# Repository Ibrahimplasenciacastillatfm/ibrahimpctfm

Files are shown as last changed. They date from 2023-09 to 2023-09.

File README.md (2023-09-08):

# ibrahimpctfm
Proyecto destinado al Diseño y Desarrollo de un Sensor IoT comunicado con Nodo Central para la Medida del Recurso Solar en Vehículos con Integración Fotovoltaica

En el repositorio se incluyen los siguientes archivos:

- Anexo_IV_Hojas_de_caracteristicas_componentes --> Enlaces a las hojas e caracteristicas de los componentes adquiridos para el diseño
- Anexo_VI_ESP32_Sensor_IoT_code.ino --> Código implementado en el sensor IoT, basado en un microcontrolador ESP32 Bluetooth & Wifi Battery (programado en Arduino IDE, C++) para la recogida de datos de irradiancia solar y temperatura empleando un módulo solar fotovoltaico de 0.3W y un termistor NTC.
- Anexo_VI_Raspi_central_node_code.py --> Código implementado en el nodo central para la recogida y registro de lso datos enviados por el sensor IoT (irradiancia solar y temperatura), así como los datos de ubicación (latitud y longitud) y orientación (magnetómetro HMC5883L) recibidos de un módulo BN-880 GPS. Basado en una Raspberry Pi 3 Model B v1.2 (programado en Python).
- ANEXO_VII_Calibracion_Modulo_Solar_Fotovoltaico --> Datos y resultados obtenidos de la calibración del Módulo Solar Fotovoltaico
-  ANEXO_VIII_Calibracion_Canales_ESP32 --> Datos y resultados obtenidos de la calibración de los canales del ESP32 empleados para la medida de la irradiancia solar y la temperatura (pines 26 y 35).
-  Archivos de diseño de la carcasa diseñada para el dispositivo sensor (en formato .ipt y .stl). El formato .ipt es el empleado por el programa Inventor Professional (se ha usado al versión 2021), mientras que el formato .stl es el empleado para las impresoras 3D. El diseño se compone de 4 piezas:
    - Pieza_base_TFM --> Parte inferior de la carcasa a la que se fija la electrónica
    - Pieza_tapa_TFM --> Parte superior de cierre del conjunto y soporte para el módulo solar fotovoltaico
    - Tapa_1_TFM --> Pieza de cierre del hueco del interruptor del ESP32
    - Tapa_2_TFM --> Pieza de cierre del hueco del conector USB del ESP32
- ANEXO_IX_Resultados_Prueba_Carretera --> Datos registrados por el sistema diseñado y desarrollado en este TFM como prueba de validación del sistema. Se corresponde con los datos recogidos en una prueba en carretera con el equipo montado en un vehículo real, bajo unas condiciones de conducción reales.

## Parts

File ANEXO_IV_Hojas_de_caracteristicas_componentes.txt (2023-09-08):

ESP32 Wifi & Bluetooth Battery
Microcontrolador del dispositivo sensor:
https://www.espressif.com/sites/default/files/documentation/esp32_datasheet_en.pdf

RS PRO, 3.7V, 18650, Lithium-Ion Rechargable Battery, 2.6Ah
Batería para el microcontrolador del dispositivo sensor
https://docs.rs-online.com/9c01/A700000008874176.pdf

Módulo Solar Fotovoltaico 100mA, 3V, 0.3W, 65x48mm
Módulo solar fotovoltaico
https://www.amazon.es/Solares-Peque%C3%B1as-C%C3%A9lulas-Proyectos-Cient%C3%ADficos/dp/B0B5XR5CQV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

Módulo AD620
Amplificador de instrumentación
https://www.amazon.es/Amplificador-Voltaje-Microvoltios-Instrumentaci%C3%B3n-Transmisor/dp/B0BQ5CYBZ4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

Termistor NTC
Sensor de temperatura
https://panda-bg.com/datasheet/918-103844-Thermistor-NTC-500mW-5-VISHAY.pdf

Raspberry Pi 3 Model B v1.2
Microcontrolador del dispositivo central
https://components101.com/sites/default/files/component_datasheet/Raspberry%20Pi%203%20Datasheet.pdf

Módulo BN-880 GPS
GPS y Brújula
https://maxterdrone.com/es/modulos-gps/1193-beitian-bn-880-gps.html

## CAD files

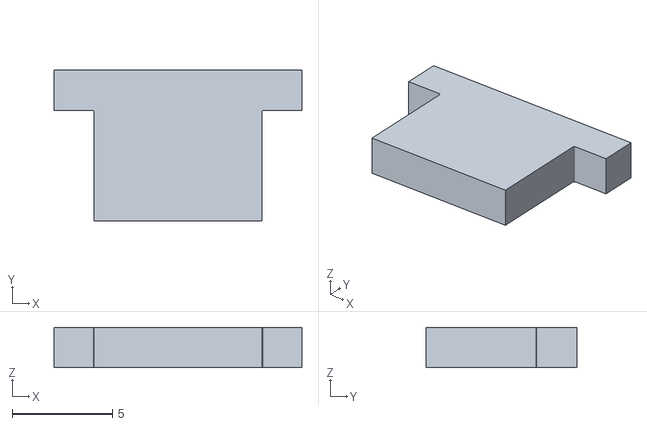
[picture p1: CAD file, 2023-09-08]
Tapa_2_TFM.stl
12.4 x 7.50 x 2.00

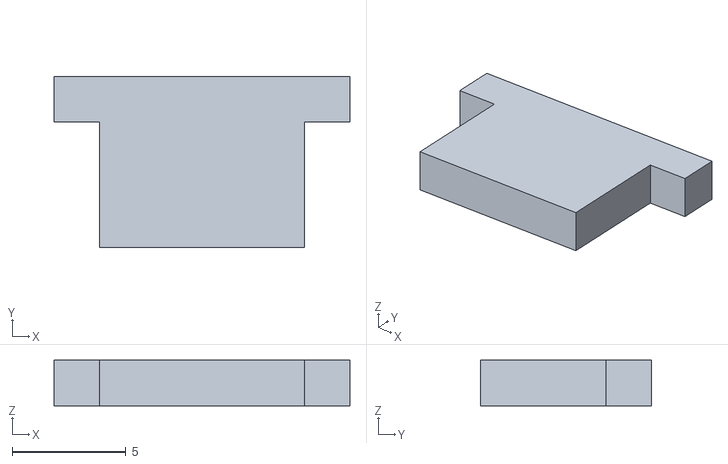
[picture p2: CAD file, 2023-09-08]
Tapa_1_TFM.stl
13.0 x 7.50 x 2.00

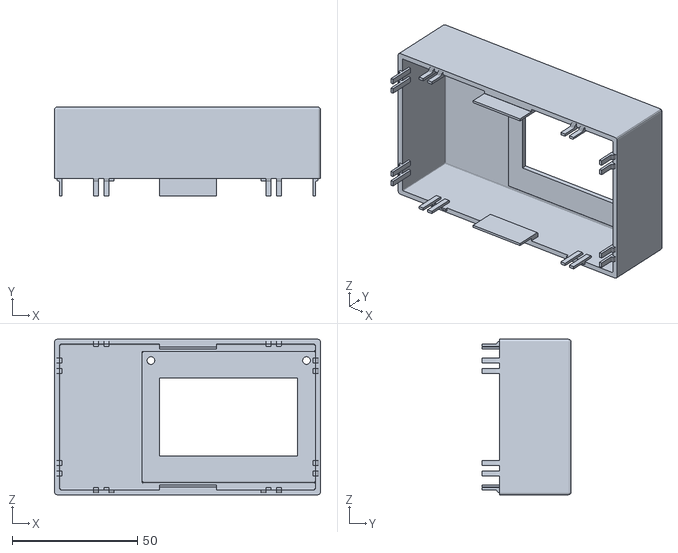
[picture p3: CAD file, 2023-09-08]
Pieza_tapa_TFM.stl
106.0 x 35.5 x 62.0

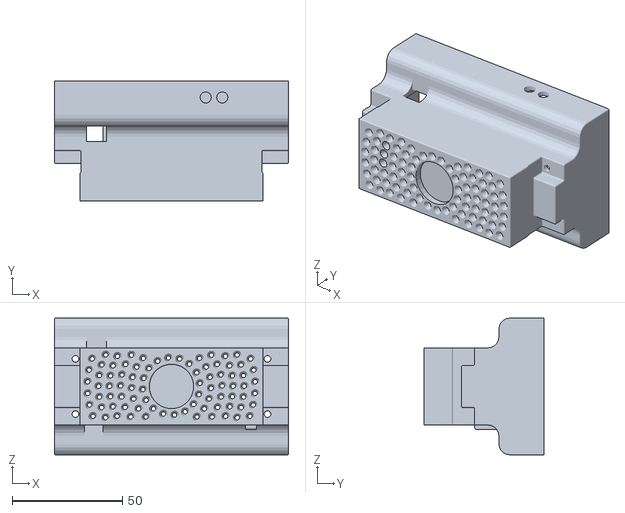
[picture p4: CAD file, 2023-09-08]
Pieza_base_TFM.stl
106.0 x 54.5 x 62.0

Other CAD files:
Pieza_base_TFM.ipt
Pieza_tapa_TFM.ipt
Tapa_1_TFM.ipt
Tapa_2_TFM.ipt

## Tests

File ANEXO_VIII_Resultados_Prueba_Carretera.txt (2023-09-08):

Datos suministrados por el nodo sensor (ESP32, vía Bluetooth), y el módulo GPS (comunicacón I2C/UART, Raspberry Pi) para el análisis de la Irradiancia Solar recibida en un Vehículo con Integración Fotovoltaica, en un determinado periodo de conducción por carretera, y estudio de la influencia de la temperatura de la célula solar en los resultados obtenidos
Fecha Hora Latitud[°] Longitud[°] Orientación Geográfica [°] IrradianciaSolar[W/m2] Temperatura[°] Desv.Temperatura[°]
09-08-2023 11:36:49 28.453197 -16.326340 183.43 S 785.77 39.74 1.36
09-08-2023 11:36:50 28.453212 -16.326331 196.82 SSO 779.25 39.17 1.35
09-08-2023 11:36:52 28.453221 -16.326325 101.48 ESE 782.51 39.47 1.35
09-08-2023 11:36:52 28.453221 -16.326325 101.48 ESE 782.51 39.47 1.35
09-08-2023 11:36:53 28.453226 -16.326326 127.57 SE 785.37 39.69 1.36
09-08-2023 11:36:53 28.453226 -16.326326 153.71 SSE 782.51 39.26 1.35
09-08-2023 11:36:54 28.453225 -16.326331 153.58 SSE 789.85 39.50 1.35
09-08-2023 11:36:56 28.453215 -16.326337 143.19 SE 789.85 39.96 1.36
09-08-2023 11:36:56 28.453215 -16.326337 143.19 SE 789.85 39.96 1.36
09-08-2023 11:36:57 28.453212 -16.326338 142.65 SE 790.67 39.99 1.36
09-08-2023 11:36:57 28.453212 -16.326338 140.72 SE 791.89 41.10 1.38
09-08-2023 11:36:58 28.453204 -16.326347 132.13 SE 791.89 40.10 1.36
09-08-2023 11:37:00 28.453196 -16.326351 137.66 SE 789.85 39.53 1.36
09-08-2023 11:37:00 28.453196 -16.326351 137.66 SE 789.85 39.53 1.36
09-08-2023 11:37:01 28.453195 -16.326348 128.62 SE 787.00 40.40 1.36
09-08-2023 11:37:01 28.453195 -16.326348 165.15 SSE 785.77 39.01 1.35
09-08-2023 11:37:02 28.453191 -16.326350 323.65 NO 783.73 39.44 1.35
09-08-2023 11:37:04 28.453190 -16.326353 312.21 NO 778.84 39.96 1.36
09-08-2023 11:37:04 28.453190 -16.326353 312.21 NO 778.84 39.96 1.36
09-08-2023 11:37:05 28.453186 -16.326356 318.79 NO 776.80 40.43 1.36
09-08-2023 11:37:05 28.453186 -16.326356 316.00 NO 789.85 41.71 1.39
09-08-2023 11:37:06 28.453191 -16.326345 299.41 ONO 776.80 40.68 1.37
09-08-2023 11:37:08 28.453187 -16.326340 283.62 ONO 798.01 41.07 1.38
09-08-2023 11:37:08 28.453187 -16.326340 283.62 ONO 798.01 41.07 1.38
09-08-2023 11:37:09 28.453194 -16.326333 246.41 OSO 797.20 40.90 1.37
09-08-2023 11:37:09 28.453194 -16.326333 235.27 SO 794.34 41.32 1.38
09-08-2023 11:37:10 28.453189 -16.326345 226.10 SO 791.08 39.23 1.35
09-08-2023 11:37:12 28.453185 -16.326348 254.42 OSO 792.30 39.85 1.36
09-08-2023 11:37:12 28.453185 -16.326348 254.42 OSO 792.30 39.85 1.36
09-08-2023 11:37:13 28.453189 -16.326350 210.32 SSO 804.95 40.48 1.36
09-08-2023 11:37:13 28.453189 -16.326350 166.13 SSE 802.91 39.47 1.35
09-08-2023 11:37:14 28.453200 -16.326342 145.23 SE 793.93 41.66 1.39
09-08-2023 11:37:16 28.453207 -16.326334 159.97 SSE 795.97 38.69 1.34
09-08-2023 11:37:16 28.453207 -16.326334 159.97 SSE 795.97 38.69 1.34
09-08-2023 11:37:17 28.453220 -16.326325 169.51 S 797.61 39.58 1.36
09-08-2023 11:37:17 28.453220 -16.326325 182.46 S 810.25 39.80 1.36
09-08-2023 11:37:18 28.453215 -16.326337 218.40 SO 798.01 42.57 1.40
09-08-2023 11:37:20 28.453227 -16.326327 208.87 SSO 802.50 40.93 1.37
09-08-2023 11:37:20 28.453227 -16.326327 208.87 SSO 802.50 40.93 1.37
09-08-2023 11:37:21 28.453215 -16.326332 224.61 SO 796.79 41.35 1.38
09-08-2023 11:37:21 28.453215 -16.326332 221.49 SO 784.55 38.32 1.34
09-08-2023 11:37:22 28.453193 -16.326346 243.09 OSO 789.04 42.48 1.40
09-08-2023 11:37:24 28.453182 -16.326355 241.56 OSO 782.92 41.01 1.38
09-08-2023 11:37:24 28.453182 -16.326355 241.56 OSO 782.92 41.01 1.38
09-08-2023 11:37:25 28.453157 -16.326372 246.49 OSO 785.37 40.84 1.37
09-08-2023 11:37:25 28.453157 -16.326372 244.10 OSO 795.97 43.09 1.41
09-08-2023 11:37:26 28.453149 -16.326379 249.01 OSO 786.18 40.24 1.36
09-08-2023 11:37:28 28.453134 -16.326388 245.81 OSO 792.30 42.62 1.40
09-08-2023 11:37:28 28.453134 -16.326388 245.81 OSO 792.30 42.62 1.40
09-08-2023 11:37:29 28.453112 -16.326397 246.08 OSO 790.26 37.92 1.33
09-08-2023 11:37:29 28.453112 -16.326397 246.90 OSO 793.93 39.17 1.35
09-08-2023 11:37:30 28.453088 -16.326412 248.86 OSO 789.45 40.59 1.37
09-08-2023 11:37:32 28.453099 -16.326407 248.48 OSO 798.83 38.13 1.33
09-08-2023 11:37:32 28.453099 -16.326407 248.48 OSO 798.83 38.13 1.33
09-08-2023 11:37:33 28.453093 -16.326409 249.23 OSO 782.92 42.80 1.40
09-08-2023 11:37:33 28.453093 -16.326409 249.88 OSO 789.85 37.89 1.33
09-08-2023 11:37:34 28.453094 -16.326408 250.14 OSO 797.61 40.43 1.36
09-08-2023 11:37:36 28.453094 -16.326408 250.04 OSO 796.79 40.62 1.37
09-08-2023 11:37:36 28.453094 -16.326408 250.04 OSO 796.79 40.62 1.37
09-08-2023 11:37:37 28.453063 -16.326435 251.66 OSO 796.79 41.63 1.39
09-08-2023 11:37:37 28.453063 -16.326435 258.90 O 789.45 39.88 1.36
09-08-2023 11:37:38 28.453023 -16.326455 157.83 SSE 787.41 39.36 1.35
09-08-2023 11:37:40 28.453029 -16.326446 142.64 SE 789.45 40.35 1.36
09-08-2023 11:37:40 28.453029 -16.326446 142.64 SE 789.45 40.35 1.36
09-08-2023 11:37:41 28.453046 -16.326442 138.26 SE 794.75 40.02 1.36
09-08-2023 11:37:41 28.453046 -16.326442 137.25 SE 794.75 41.04 1.38
09-08-2023 11:37:42 28.453077 -16.326421 137.07 SE 797.20 41.43 1.38
09-08-2023 11:37:44 28.453085 -16.326415 142.64 SE 797.20 39.17 1.35
09-08-2023 11:37:44 28.453085 -16.326415 142.64 SE 797.20 39.17 1.35
09-08-2023 11:37:45 28.453091 -16.326408 140.28 SE 794.34 41.23 1.38
09-08-2023 11:37:45 28.453091 -16.326408 142.04 SE 795.97 41.29 1.38
09-08-2023 11:37:46 28.453102 -16.326395 142.19 SE 802.91 40.62 1.37
09-08-2023 11:37:48 28.453114 -16.326392 142.87 SE 803.73 41.77 1.39
09-08-2023 11:37:48 28.453114 -16.326392 142.87 SE 803.73 41.77 1.39
09-08-2023 11:37:49 28.453125 -16.326396 144.92 SE 804.95 40.32 1.36
09-08-2023 11:37:49 28.453125 -16.326396 144.92 SE 805.77 39.31 1.35
09-08-2023 11:37:50 28.453138 -16.326396 147.40 SSE 804.95 40.04 1.36
09-08-2023 11:37:52 28.453144 -16.326392 147.15 SSE 808.62 41.32 1.38
09-08-2023 11:37:52 28.453144 -16.326392 147.15 SSE 808.62 41.32 1.38
09-08-2023 11:37:53 28.453147 -16.326386 148.01 SSE 804.95 40.93 1.37
09-08-2023 11:37:53 28.453147 -16.326386 151.07 SSE 806.58 39.85 1.36
09-08-2023 11:37:54 28.453136 -16.326376 155.45 SSE 802.50 41.26 1.38
09-08-2023 11:37:56 28.453126 -16.326366 159.79 SSE 795.16 40.04 1.36
09-08-2023 11:37:56 28.453126 -16.326366 159.79 SSE 795.16 40.04 1.36
09-08-2023 11:37:57 28.453115 -16.326351 154.68 SSE 799.24 40.79 1.37
09-08-2023 11:37:57 28.453115 -16.326351 152.55 SSE 783.33 40.04 1.36
09-08-2023 11:37:58 28.453088 -16.326287 147.07 SSE 790.26 41.54 1.38
09-08-2023 11:38:00 28.453062 -16.326240 144.55 SE 782.92 40.87 1.37
09-08-2023 11:38:00 28.453062 -16.326240 144.55 SE 782.92 40.87 1.37
09-08-2023 11:38:01 28.453017 -16.326193 144.65 SE 781.29 40.68 1.37
09-08-2023 11:38:01 28.453017 -16.326193 144.92 SE 780.47 40.87 1.37
09-08-2023 11:38:02 28.452945 -16.326085 145.31 SE 785.77 39.17 1.35
09-08-2023 11:38:04 28.452910 -16.326030 144.34 SE 782.92 41.68 1.39
09-08-2023 11:38:04 28.452910 -16.326030 144.34 SE 782.92 41.68 1.39
09-08-2023 11:38:05 28.452866 -16.325971 144.04 SE 764.97 40.76 1.37
09-08-2023 11:38:05 28.452866 -16.325971 144.35 SE 772.31 40.29 1.36
09-08-2023 11:38:06 28.452795 -16.325852 142.43 SE 760.07 40.24 1.36
09-08-2023 11:38:08 28.452746 -16.325804 142.29 SE 793.93 42.71 1.40
09-08-2023 11:38:08 28.452746 -16.325804 142.29 SE 793.93 42.71 1.40
09-08-2023 11:38:09 28.452712 -16.325763 139.41 SE 800.05 41.35 1.38
09-08-2023 11:38:09 28.452712 -16.325763 135.42 SE 789.04 40.51 1.37
09-08-2023 11:38:10 28.452656 -16.325694 120.26 ESE 789.45 40.76 1.37
09-08-2023 11:38:12 28.452627 -16.325659 97.45 E 771.90 42.45 1.40
09-08-2023 11:38:12 28.452627 -16.325659 97.45 E 771.90 42.45 1.40
09-08-2023 11:38:13 28.452627 -16.325606 75.27 ENE 749.06 40.84 1.37
09-08-2023 11:38:13 28.452627 -16.325606 62.93 ENE 761.70 41.46 1.38
09-08-2023 11:38:14 28.452714 -16.325524 67.05 ENE 722.54 40.43 1.36
09-08-2023 11:38:16 28.452770 -16.325493 60.07 ENE 64.87 41.52 1.38
09-08-2023 11:38:16 28.452770 -16.325493 60.07 ENE 64.87 41.52 1.38
09-08-2023 11:38:17 28.452801 -16.325451 64.33 ENE 39.57 40.68 1.37
09-08-2023 11:38:17 28.452801 -16.325451 59.56 ENE 39.57 41.40 1.38
09-08-2023 11:38:18 28.452880 -16.325368 58.34 ENE 58.75 40.73 1.37
09-08-2023 11:38:20 28.452963 -16.325324 60.55 ENE 735.59 41.35 1.38
09-08-2023 11:38:20 28.452963 -16.325324 60.55 ENE 735.59 41.35 1.38
09-08-2023 11:38:21 28.453042 -16.325278 63.45 ENE 743.75 40.02 1.36
09-08-2023 11:38:21 28.453042 -16.325278 63.12 ENE 731.10 40.90 1.37
09-08-2023 11:38:22 28.453149 -16.325196 63.95 ENE 734.78 41.40 1.38
09-08-2023 11:38:24 28.453201 -16.325154 54.09 NE 838.40 37.52 1.32
09-08-2023 11:38:24 28.453201 -16.325154 54.09 NE 838.40 37.52 1.32
09-08-2023 11:38:25 28.453251 -16.325151 29.04 NNE 784.96 42.28 1.40
09-08-2023 11:38:25 28.453251 -16.325151 7.29 N 736.00 41.10 1.38
09-08-2023 11:38:26 28.453350 -16.325134 339.70 NNO 751.10 42.00 1.39
09-08-2023 11:38:28 28.453386 -16.325144 311.02 NO 814.74 42.42 1.40
09-08-2023 11:38:28 28.453386 -16.325144 311.02 NO 814.74 42.42 1.40
09-08-2023 11:38:29 28.453416 -16.325156 302.87 ONO 1070.95 36.79 1.31
09-08-2023 11:38:29 28.453416 -16.325156 303.10 ONO 1044.03 38.72 1.34
09-08-2023 11:38:30 28.453461 -16.325214 308.32 NO 1056.67 34.55 1.29
09-08-2023 11:38:32 28.453489 -16.325238 304.78 NO 676.84 40.37 1.36
09-08-2023 11:38:32 28.453489 -16.325238 304.78 NO 676.84 40.37 1.36
09-08-2023 11:38:33 28.453537 -16.325283 310.18 NO 650.73 40.79 1.37
09-08-2023 11:38:33 28.453537 -16.325283 307.12 NO 642.57 41.35 1.38
09-08-2023 11:38:34 28.453605 -16.325397 309.00 NO 674.39 40.24 1.36
09-08-2023 11:38:36 28.453641 -16.325458 311.80 NO 682.96 39.01 1.35
09-08-2023 11:38:36 28.453641 -16.325458 311.80 NO 682.96 39.01 1.35
09-08-2023 11:38:37 28.453681 -16.325514 312.28 NO 748.65 37.92 1.33
09-08-2023 11:38:37 28.453681 -16.325514 306.37 NO 815.96 41.74 1.39
09-08-2023 11:38:38 28.453750 -16.325654 304.07 NO 860.43 40.24 1.36
09-08-2023 11:38:40 28.453763 -16.325722 296.00 ONO 776.80 43.12 1.41
09-08-2023 11:38:40 28.453763 -16.325722 296.00 ONO 776.80 43.12 1.41
09-08-2023 11:38:41 28.453789 -16.325780 284.18 ONO 915.92 43.91 1.42
09-08-2023 11:38:41 28.453789 -16.325780 281.37 ONO 145.65 39.69 1.36
09-08-2023 11:38:42 28.453831 -16.325935 279.39 O 848.20 41.38 1.38
09-08-2023 11:38:44 28.453867 -16.326018 280.14 O 700.10 40.40 1.36
09-08-2023 11:38:44 28.453867 -16.326018 280.14 O 700.10 40.40 1.36
09-08-2023 11:38:45 28.453891 -16.326111 276.99 O 313.33 41.18 1.38
09-08-2023 11:38:45 28.453891 -16.326111 274.05 O 724.58 39.44 1.35
09-08-2023 11:38:46 28.453910 -16.326256 273.74 O 704.99 39.69 1.36
09-08-2023 11:38:48 28.453903 -16.326324 274.64 O 684.19 39.42 1.35
09-08-2023 11:38:48 28.453903 -16.326324 274.64 O 684.19 39.42 1.35
09-08-2023 11:38:49 28.453892 -16.326374 277.87 O 68.13 40.32 1.36
09-08-2023 11:38:49 28.453892 -16.326374 274.86 O 117.91 39.01 1.35
09-08-2023 11:38:50 28.453929 -16.326488 279.24 O 704.18 38.29 1.34
09-08-2023 11:38:52 28.453934 -16.326548 277.80 O 694.79 40.32 1.36
09-08-2023 11:38:52 28.453934 -16.326548 277.80 O 694.79 40.32 1.36
09-08-2023 11:38:53 28.453945 -16.326614 277.47 O 693.16 38.34 1.34
09-08-2023 11:38:53 28.453945 -16.326614 277.01 O 680.11 38.45 1.34
09-08-2023 11:38:54 28.453992 -16.326760 283.48 ONO 709.48 39.15 1.35
09-08-2023 11:38:56 28.454018 -16.326830 278.57 O 693.57 38.74 1.34
09-08-2023 11:38:56 28.454018 -16.326830 278.57 O 693.57 38.74 1.34
09-08-2023 11:38:57 28.454026 -16.326893 281.22 O 688.27 38.90 1.34
09-08-2023 11:38:57 28.454026 -16.326893 283.27 ONO 137.49 39.42 1.35
09-08-2023 11:38:58 28.454093 -16.326995 280.17 O 688.27 38.85 1.34
09-08-2023 11:38:59 28.454095 -16.327042 278.19 O 673.58 39.26 1.35
09-08-2023 11:38:59 28.454095 -16.327042 278.19 O 673.58 39.26 1.35
09-08-2023 11:39:01 28.454116 -16.327099 279.02 O 683.78 38.56 1.34
09-08-2023 11:39:01 28.454116 -16.327099 280.52 O 625.03 38.58 1.34
09-08-2023 11:39:02 28.454163 -16.327230 285.39 ONO 685.41 38.88 1.34
09-08-2023 11:39:04 28.454210 -16.327293 289.62 ONO 692.35 38.74 1.34
09-08-2023 11:39:04 28.454210 -16.327293 289.62 ONO 692.35 38.74 1.34
09-08-2023 11:39:05 28.454271 -16.327363 292.76 ONO 92.61 38.61 1.34
09-08-2023 11:39:05 28.454271 -16.327363 295.23 ONO 92.61 38.45 1.34
09-08-2023 11:39:06 28.454347 -16.327511 294.35 ONO 137.08 38.64 1.34
09-08-2023 11:39:08 28.454385 -16.327591 292.24 ONO 678.47 38.66 1.34
09-08-2023 11:39:08 28.454385 -16.327591 292.24 ONO 678.47 38.66 1.34
09-08-2023 11:39:09 28.454432 -16.327679 299.74 ONO 32.64 38.37 1.34
09-08-2023 11:39:09 28.454432 -16.327679 300.39 ONO 657.26 38.66 1.34
09-08-2023 11:39:10 28.454531 -16.327841 299.74 ONO 657.26 38.29 1.34
09-08-2023 11:39:12 28.454568 -16.327938 293.84 ONO 128.51 38.74 1.34
09-08-2023 11:39:12 28.454568 -16.327938 293.84 ONO 128.51 38.74 1.34
09-08-2023 11:39:13 28.454606 -16.328025 292.73 ONO 89.35 38.24 1.33
09-08-2023 11:39:13 28.454606 -16.328025 285.83 ONO 662.97 38.40 1.34
09-08-2023 11:39:14 28.454712 -16.328226 276.74 O 214.60 38.24 1.33
09-08-2023 11:39:16 28.454747 -16.328315 272.30 O 672.35 38.61 1.34
09-08-2023 11:39:16 28.454747 -16.328315 272.30 O 672.35 38.61 1.34
09-08-2023 11:39:17 28.454790 -16.328427 270.37 O 683.37 38.03 1.33
09-08-2023 11:39:17 28.454790 -16.328427 269.47 O 192.98 37.73 1.33
09-08-2023 11:39:18 28.454856 -16.328673 267.03 O 671.95 37.87 1.33
09-08-2023 11:39:20 28.454902 -16.328796 269.05 O 679.29 36.79 1.31
09-08-2023 11:39:20 28.454902 -16.328796 269.05 O 679.29 36.79 1.31
09-08-2023 11:39:21 28.454935 -16.328917 267.54 O 666.64 38.77 1.34
09-08-2023 11:39:21 28.454935 -16.328917 269.22 O 682.55 37.60 1.33
09-08-2023 11:39:22 28.455013 -16.329169 263.26 O 670.32 37.55 1.32
09-08-2023 11:39:24 28.455046 -16.329293 268.67 O 665.42 37.45 1.32
09-08-2023 11:39:24 28.455046 -16.329293 268.67 O 665.42 37.45 1.32
09-08-2023 11:39:25 28.455086 -16.329421 266.27 O 683.37 37.39 1.32
09-08-2023 11:39:25 28.455086 -16.329421 272.24 O 679.29 37.42 1.32
09-08-2023 11:39:26 28.455157 -16.329669 270.23 O 691.53 37.55 1.32
09-08-2023 11:39:28 28.455192 -16.329783 273.14 O 682.96 37.45 1.32
09-08-2023 11:39:28 28.455192 -16.329783 273.14 O 682.96 37.45 1.32
09-08-2023 11:39:29 28.455235 -16.329895 269.93 O 687.86 37.00 1.32
09-08-2023 11:39:29 28.455235 -16.329895 272.20 O 58.34 37.05 1.32
09-08-2023 11:39:30 28.455301 -16.330079 275.73 O 694.79 37.31 1.32
09-08-2023 11:39:32 28.455333 -16.330158 274.65 O 694.79 36.82 1.31
09-08-2023 11:39:32 28.455333 -16.330158 274.65 O 694.79 36.82 1.31
09-08-2023 11:39:33 28.455358 -16.330220 276.05 O 697.65 37.13 1.32
09-08-2023 11:39:33 28.455358 -16.330220 274.88 O 691.53 36.72 1.31
09-08-2023 11:39:34 28.455406 -16.330285 272.26 O 694.79 36.46 1.31
09-08-2023 11:39:36 28.455425 -16.330304 280.21 O 673.17 36.69 1.31
09-08-2023 11:39:36 28.455425 -16.330304 280.21 O 673.17 36.69 1.31
09-08-2023 11:39:37 28.455437 -16.330321 285.84 ONO 674.39 35.74 1.30
09-08-2023 11:39:37 28.455437 -16.330321 289.12 ONO 674.39 36.66 1.31
09-08-2023 11:39:38 28.455450 -16.330355 287.38 ONO 673.99 35.69 1.30
09-08-2023 11:39:40 28.455457 -16.330370 299.51 ONO 678.47 35.92 1.30
09-08-2023 11:39:40 28.455457 -16.330370 299.51 ONO 678.47 35.92 1.30
09-08-2023 11:39:40 28.455471 -16.330382 304.99 NO 687.45 36.41 1.31
09-08-2023 11:39:41 28.455471 -16.330382 306.04 NO 687.04 36.41 1.31
09-08-2023 11:39:42 28.455482 -16.330408 301.63 ONO 673.17 36.43 1.31
09-08-2023 11:39:44 28.455487 -16.330418 300.80 ONO 675.21 36.98 1.32
09-08-2023 11:39:44 28.455487 -16.330418 300.80 ONO 675.21 36.98 1.32
09-08-2023 11:39:45 28.455488 -16.330424 299.50 ONO 676.43 35.66 1.30
09-08-2023 11:39:45 28.455488 -16.330424 299.68 ONO 681.74 36.82 1.31
09-08-2023 11:39:46 28.455486 -16.330446 299.20 ONO 679.29 37.08 1.32
09-08-2023 11:39:48 28.455491 -16.330459 302.32 ONO 676.84 37.50 1.32
09-08-2023 11:39:48 28.455491 -16.330459 302.32 ONO 676.84 37.50 1.32
09-08-2023 11:39:49 28.455492 -16.330461 304.15 NO 678.88 36.72 1.31
09-08-2023 11:39:49 28.455492 -16.330461 303.04 ONO 679.29 36.90 1.32
09-08-2023 11:39:50 28.455489 -16.330466 303.77 NO 680.51 36.98 1.32
09-08-2023 11:39:52 28.455492 -16.330478 300.81 ONO 691.53 36.82 1.31
09-08-2023 11:39:52 28.455492 -16.330478 300.81 ONO 691.53 36.82 1.31
09-08-2023 11:39:53 28.455493 -16.330484 303.17 ONO 677.25 36.56 1.31
09-08-2023 11:39:53 28.455493 -16.330484 302.21 ONO 672.76 36.35 1.31
09-08-2023 11:39:54 28.455496 -16.330497 299.67 ONO 674.80 36.98 1.32
09-08-2023 11:39:56 28.455499 -16.330503 312.51 NO 689.49 36.98 1.32
09-08-2023 11:39:56 28.455499 -16.330503 312.51 NO 689.49 36.98 1.32
09-08-2023 11:39:57 28.455512 -16.330518 338.74 NNO 676.43 36.64 1.31
09-08-2023 11:39:57 28.455512 -16.330518 358.62 N 672.76 37.47 1.32
09-08-2023 11:39:58 28.455589 -16.330534 33.84 NE 674.39 36.30 1.31
09-08-2023 11:40:00 28.455646 -16.330531 37.67 NE 678.88 36.87 1.31
09-08-2023 11:40:00 28.455646 -16.330531 37.67 NE 678.88 36.87 1.31
09-08-2023 11:40:01 28.455700 -16.330513 40.72 NE 665.01 37.42 1.32
09-08-2023 11:40:01 28.455700 -16.330513 50.11 NE 663.38 36.87 1.31
09-08-2023 11:40:02 28.455817 -16.330460 49.72 NE 672.35 36.59 1.31
09-08-2023 11:40:04 28.455872 -16.330437 55.94 NE 676.03 37.00 1.32
09-08-2023 11:40:04 28.455872 -16.330437 55.94 NE 676.03 37.00 1.32
09-08-2023 11:40:05 28.455933 -16.330403 60.33 ENE 664.60 36.35 1.31
09-08-2023 11:40:05 28.455933 -16.330403 60.22 ENE 659.71 36.72 1.31
09-08-2023 11:40:06 28.456059 -16.330290 62.39 ENE 659.30 36.38 1.31
09-08-2023 11:40:08 28.456129 -16.330238 60.87 ENE 661.34 36.64 1.31
09-08-2023 11:40:08 28.456129 -16.330238 60.87 ENE 661.34 36.64 1.31
09-08-2023 11:40:09 28.456196 -16.330185 63.21 ENE 659.71 36.79 1.31
09-08-2023 11:40:09 28.456196 -16.330185 61.42 ENE 671.95 37.24 1.32
09-08-2023 11:40:10 28.456337 -16.330077 60.96 ENE 672.35 35.74 1.30
09-08-2023 11:40:12 28.456404 -16.330029 66.42 ENE 663.38 36.59 1.31
09-08-2023 11:40:12 28.456404 -16.330029 66.42 ENE 663.38 36.59 1.31
09-08-2023 11:40:13 28.456469 -16.329980 68.45 ENE 678.88 36.38 1.31
09-08-2023 11:40:13 28.456469 -16.329980 66.60 ENE 671.54 35.82 1.30
09-08-2023 11:40:14 28.456596 -16.329897 60.07 ENE 667.05 36.98 1.32
09-08-2023 11:40:16 28.456660 -16.329851 64.67 ENE 659.30 35.87 1.30
09-08-2023 11:40:16 28.456660 -16.329851 64.67 ENE 659.30 35.87 1.30
09-08-2023 11:40:17 28.456723 -16.329807 62.79 ENE 663.79 37.13 1.32
09-08-2023 11:40:17 28.456723 -16.329807 63.69 ENE 667.05 35.89 1.30
09-08-2023 11:40:18 28.456852 -16.329719 63.42 ENE 674.80 36.35 1.31
09-08-2023 11:40:20 28.456919 -16.329670 63.10 ENE 667.87 35.82 1.30
09-08-2023 11:40:20 28.456919 -16.329670 63.10 ENE 667.87 35.82 1.30
09-08-2023 11:40:21 28.456989 -16.329619 64.03 ENE 661.75 35.82 1.30
09-08-2023 11:40:21 28.456989 -16.329619 66.33 ENE 660.52 36.87 1.31
09-08-2023 11:40:22 28.457129 -16.329514 62.38 ENE 665.83 36.64 1.31
09-08-2023 11:40:24 28.457201 -16.329460 60.84 ENE 668.68 35.79 1.30
09-08-2023 11:40:24 28.457201 -16.329460 60.84 ENE 668.68 35.79 1.30
09-08-2023 11:40:25 28.457276 -16.329410 56.51 ENE 660.52 36.61 1.31
09-08-2023 11:40:25 28.457276 -16.329410 55.60 NE 424.71 36.25 1.31
09-08-2023 11:40:26 28.457430 -16.329323 49.99 NE 652.36 36.66 1.31
09-08-2023 11:40:28 28.457507 -16.329288 50.33 NE 661.34 36.30 1.31
09-08-2023 11:40:28 28.457507 -16.329288 50.33 NE 661.34 36.30 1.31
09-08-2023 11:40:29 28.457586 -16.329255 47.61 NE 657.26 36.92 1.32
09-08-2023 11:40:29 28.457586 -16.329255 49.04 NE 655.63 36.66 1.31
09-08-2023 11:40:30 28.457732 -16.329197 48.22 NE 657.67 35.82 1.30
09-08-2023 11:40:32 28.457802 -16.329169 46.01 NE 664.20 36.53 1.31
09-08-2023 11:40:32 28.457802 -16.329169 46.01 NE 664.20 36.53 1.31
09-08-2023 11:40:33 28.457870 -16.329142 46.58 NE 666.64 35.82 1.30
09-08-2023 11:40:33 28.457870 -16.329142 46.38 NE 97.92 35.87 1.30
09-08-2023 11:40:34 28.457986 -16.329097 34.96 NE 685.41 35.82 1.30
09-08-2023 11:40:36 28.458037 -16.329077 44.39 NE 663.79 36.25 1.31
09-08-2023 11:40:36 28.458037 -16.329077 44.39 NE 663.79 36.25 1.31
09-08-2023 11:40:37 28.458076 -16.329061 42.84 NE 658.08 36.41 1.31
09-08-2023 11:40:37 28.458076 -16.329061 43.82 NE 659.30 36.25 1.31
09-08-2023 11:40:38 28.458142 -16.329037 46.53 NE 658.48 35.00 1.29
09-08-2023 11:40:40 28.458166 -16.329026 49.69 NE 658.08 36.64 1.31
09-08-2023 11:40:40 28.458166 -16.329026 49.69 NE 658.08 36.64 1.31
09-08-2023 11:40:41 28.458182 -16.329017 48.63 NE 658.08 36.25 1.31
09-08-2023 11:40:41 28.458182 -16.329017 47.42 NE 667.46 35.89 1.30
09-08-2023 11:40:42 28.458191 -16.329015 47.84 NE 661.34 35.56 1.30
09-08-2023 11:40:44 28.458188 -16.329015 49.24 NE 660.12 35.28 1.29
09-08-2023 11:40:44 28.458188 -16.329015 49.24 NE 660.12 35.28 1.29
09-08-2023 11:40:45 28.458186 -16.329015 47.84 NE 660.52 36.87 1.31
09-08-2023 11:40:45 28.458186 -16.329015 48.43 NE 661.75 35.94 1.30
09-08-2023 11:40:46 28.458183 -16.329014 48.23 NE 671.95 36.61 1.31
09-08-2023 11:40:48 28.458182 -16.329013 46.43 NE 661.75 36.64 1.31
09-08-2023 11:40:48 28.458182 -16.329013 46.43 NE 661.75 36.64 1.31
09-08-2023 11:40:49 28.458181 -16.329013 46.86 NE 660.93 36.35 1.31
09-08-2023 11:40:49 28.458181 -16.329013 48.23 NE 671.95 35.64 1.30
09-08-2023 11:40:50 28.458177 -16.329012 45.84 NE 661.34 35.05 1.29
09-08-2023 11:40:52 28.458181 -16.329009 47.62 NE 663.79 36.38 1.31
09-08-2023 11:40:52 28.458181 -16.329009 47.62 NE 663.79 36.38 1.31
09-08-2023 11:40:53 28.458199 -16.329003 47.24 NE 669.91 36.30 1.31
09-08-2023 11:40:53 28.458199 -16.329003 48.02 NE 659.30 36.33 1.31
09-08-2023 11:40:54 28.458276 -16.328974 48.09 NE 663.79 35.15 1.29
09-08-2023 11:40:56 28.458319 -16.328955 46.17 NE 673.17 36.46 1.31
09-08-2023 11:40:56 28.458319 -16.328955 46.17 NE 673.17 36.46 1.31
09-08-2023 11:40:56 28.458364 -16.328937 49.65 NE 669.91 35.82 1.30
09-08-2023 11:40:57 28.458364 -16.328937 47.05 NE 676.03 35.05 1.29
09-08-2023 11:40:58 28.458470 -16.328885 43.31 NE 683.37 35.87 1.30
09-08-2023 11:41:00 28.458536 -16.328864 46.56 NE 672.76 36.90 1.32
09-08-2023 11:41:00 28.458536 -16.328864 46.56 NE 672.76 36.90 1.32
09-08-2023 11:41:01 28.458611 -16.328843 40.47 NE 681.74 35.48 1.29
09-08-2023 11:41:01 28.458611 -16.328843 40.72 NE 681.74 36.46 1.31
09-08-2023 11:41:02 28.458772 -16.328791 44.90 NE 685.41 35.53 1.30
09-08-2023 11:41:04 28.458858 -16.328763 45.02 NE 672.35 35.05 1.29
09-08-2023 11:41:04 28.458858 -16.328763 45.02 NE 672.35 35.05 1.29
09-08-2023 11:41:05 28.458942 -16.328737 41.25 NE 674.80 35.64 1.30
09-08-2023 11:41:05 28.458942 -16.328737 44.64 NE 687.45 34.57 1.29
09-08-2023 11:41:06 28.459099 -16.328684 43.76 NE 681.33 34.60 1.29
09-08-2023 11:41:08 28.459167 -16.328668 43.96 NE 693.98 36.64 1.31
09-08-2023 11:41:08 28.459167 -16.328668 43.96 NE 693.98 36.64 1.31
09-08-2023 11:41:09 28.459229 -16.328648 42.14 NE 690.71 35.20 1.29
09-08-2023 11:41:09 28.459229 -16.328648 39.78 NE 691.53 37.08 1.32
09-08-2023 11:41:10 28.459341 -16.328623 42.88 NE 693.16 34.50 1.28
09-08-2023 11:41:12 28.459392 -16.328613 40.46 NE 713.97 38.45 1.34
09-08-2023 11:41:12 28.459392 -16.328613 40.46 NE 713.97 38.45 1.34
09-08-2023 11:41:13 28.459442 -16.328607 30.33 NNE 712.34 35.56 1.30
09-08-2023 11:41:13 28.459442 -16.328607 32.60 NNE 747.02 38.32 1.34
09-08-2023 11:41:14 28.459542 -16.328597 32.65 NNE 724.98 35.69 1.30
09-08-2023 11:41:16 28.459588 -16.328596 31.60 NNE 709.07 37.71 1.33
09-08-2023 11:41:16 28.459588 -16.328596 31.60 NNE 709.07 37.71 1.33
09-08-2023 11:41:17 28.459624 -16.328601 29.64 NNE 720.09 37.03 1.32
09-08-2023 11:41:17 28.459624 -16.328601 31.40 NNE 719.68 37.47 1.32
09-08-2023 11:41:18 28.459694 -16.328597 31.31 NNE 707.44 34.42 1.28
09-08-2023 11:41:20 28.459732 -16.328588 33.13 NNE 688.27 35.59 1.30
09-08-2023 11:41:20 28.459732 -16.328588 33.13 NNE 688.27 35.59 1.30
09-08-2023 11:41:21 28.459771 -16.328588 34.19 NE 689.90 34.70 1.29
09-08-2023 11:41:21 28.459771 -16.328588 37.23 NE 691.94 34.57 1.29
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

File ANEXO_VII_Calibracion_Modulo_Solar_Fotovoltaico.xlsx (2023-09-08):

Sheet: 230724-111650
Vendor,GRAPHTEC Corporation
Model,GL100
Firmware,Ver1.45
Software, "Ver1.31"
Sampling,1s
Total data points,7762
Trigger,0
Start time,2023-07-24,11:16:50
Stop time,2023-07-24,13:26:13
Trigger time,2023-07-24,11:16:51
AC Mode,
Logic/Pulse,Off
Amp setting
CH, Signal name, Input, Range, Filter, Span
CH1,CH 1,DC,50mV,Off,25.000000,-25.000000,mV,, | célula
CH2,CH 2,TEMP,TC_K,Off,2000.000000,-200.000000,degC | termopar ignorar
CH3,CH 3,DC,20mV,Off,10.000000,-10.000000,mV,, | piranómetro | cte calibracion 8.92 uV/(W/m2)
CH4,CH 4,DC,20mV,Off,10.000000,-10.000000,mV,, | nada
Data
No., Date&Time, ms,CH1,CH2,CH3,CH4,Alarm,AlarmOut
NO.,Time,ms,mV,degC,mV,mV,A12345678,A1
1,2023-07-24 11:16:51,000,+11.19,+30.2,+5.257,+0.257,LLLLLLLL,L
2,2023-07-24 11:16:52,000,+11.17,+30.3,+5.262,+0.084,LLLLLLLL,L
3,2023-07-24 11:16:53,000,+11.17,+30.6,+5.255,+0.220,LLLLLLLL,L
4,2023-07-24 11:16:54,000,+11.18,+30.5,+5.254,+0.141,LLLLLLLL,L
5,2023-07-24 11:16:55,000,+11.18,+29.5,+5.250,+0.143,LLLLLLLL,L
6,2023-07-24 11:16:56,000,+11.19,+28.6,+5.250,+0.109,LLLLLLLL,L
7,2023-07-24 11:16:57,000,+11.17,+27.7,+5.249,+0.158,LLLLLLLL,L
8,2023-07-24 11:16:58,000,+11.17,+27.5,+5.245,+0.180,LLLLLLLL,L
9,2023-07-24 11:16:59,000,+11.17,+27.4,+5.247,+0.129,LLLLLLLL,L
10,2023-07-24 11:17:00,000,+11.17,+27.7,+5.249,+0.153,LLLLLLLL,L
11,2023-07-24 11:17:01,000,+11.15,+27.4,+5.249,+0.148,LLLLLLLL,L
12,2023-07-24 11:17:02,000,+11.16,+27.4,+5.251,+0.131,LLLLLLLL,L
13,2023-07-24 11:17:03,000,+11.16,+27.7,+5.251,+0.134,LLLLLLLL,L
14,2023-07-24 11:17:04,000,+11.16,+27.9,+5.248,+0.127,LLLLLLLL,L
15,2023-07-24 11:17:05,000,+11.17,+27.5,+5.249,+0.136,LLLLLLLL,L
16,2023-07-24 11:17:06,000,+11.16,+27.2,+5.249,+0.151,LLLLLLLL,L
17,2023-07-24 11:17:07,000,+11.16,+27.7,+5.251,+0.170,LLLLLLLL,L
18,2023-07-24 11:17:08,000,+11.15,+27.7,+5.251,+0.138,LLLLLLLL,L
19,2023-07-24 11:17:09,000,+11.15,+27.6,+5.252,+0.421,LLLLLLLL,L
20,2023-07-24 11:17:10,000,+11.14,+27.7,+5.256,+0.238,LLLLLLLL,L
21,2023-07-24 11:17:11,000,+11.15,+27.4,+5.252,+0.152,LLLLLLLL,L
22,2023-07-24 11:17:12,000,+11.15,+27.5,+5.254,+0.465,LLLLLLLL,L
23,2023-07-24 11:17:13,000,+11.14,+27.7,+5.253,+0.371,LLLLLLLL,L
24,2023-07-24 11:17:14,000,+11.15,+28.2,+5.255,+0.233,LLLLLLLL,L
25,2023-07-24 11:17:15,000,+11.15,+28.2,+5.254,+0.489,LLLLLLLL,L
26,2023-07-24 11:17:16,000,+11.15,+28.2,+5.255,+0.426,LLLLLLLL,L
27,2023-07-24 11:17:17,000,+11.13,+28.5,+5.256,+0.519,LLLLLLLL,L
28,2023-07-24 11:17:18,000,+11.15,+28.8,+5.254,+0.526,LLLLLLLL,L
29,2023-07-24 11:17:19,000,+11.14,+29.1,+5.255,+0.538,LLLLLLLL,L
30,2023-07-24 11:17:20,000,+11.14,+28.8,+5.254,+0.539,LLLLLLLL,L
31,2023-07-24 11:17:21,000,+11.14,+28.8,+5.254,+0.564,LLLLLLLL,L
32,2023-07-24 11:17:22,000,+11.14,+28.5,+5.260,+0.493,LLLLLLLL,L
33,2023-07-24 11:17:23,000,+11.12,+28.0,+5.262,+0.580,LLLLLLLL,L
34,2023-07-24 11:17:24,000,+11.10,+27.4,+5.255,+0.555,LLLLLLLL,L
35,2023-07-24 11:17:25,000,+11.10,+27.4,+5.255,+0.350,LLLLLLLL,L
36,2023-07-24 11:17:26,000,+11.11,+27.4,+5.255,+0.448,LLLLLLLL,L
37,2023-07-24 11:17:27,000,+11.08,+27.4,+5.255,+0.519,LLLLLLLL,L
38,2023-07-24 11:17:28,000,+11.09,+27.0,+5.258,+0.161,LLLLLLLL,L
39,2023-07-24 11:17:29,000,+11.11,+26.7,+5.261,+0.203,LLLLLLLL,L
40,2023-07-24 11:17:30,000,+11.10,+26.8,+5.262,+0.328,LLLLLLLL,L
41,2023-07-24 11:17:31,000,+11.10,+26.6,+5.262,+0.113,LLLLLLLL,L
42,2023-07-24 11:17:32,000,+11.09,+26.7,+5.262,+0.173,LLLLLLLL,L
43,2023-07-24 11:17:33,000,+11.08,+26.9,+5.261,+0.179,LLLLLLLL,L
44,2023-07-24 11:17:34,000,+11.03,+26.7,+5.264,+0.150,LLLLLLLL,L
45,2023-07-24 11:17:35,000,+11.04,+27.0,+5.265,+0.131,LLLLLLLL,L
46,2023-07-24 11:17:36,000,+11.05,+27.0,+5.265,+0.151,LLLLLLLL,L
47,2023-07-24 11:17:37,000,+11.05,+27.4,+5.268,+0.110,LLLLLLLL,L
48,2023-07-24 11:17:38,000,+11.06,+27.7,+5.267,+0.124,LLLLLLLL,L
49,2023-07-24 11:17:39,000,+11.05,+27.6,+5.269,+0.132,LLLLLLLL,L
50,2023-07-24 11:17:40,000,+11.06,+27.9,+5.270,+0.106,LLLLLLLL,L
51,2023-07-24 11:17:41,000,+11.06,+28.2,+5.267,+0.303,LLLLLLLL,L
52,2023-07-24 11:17:42,000,+11.05,+28.4,+5.267,+0.267,LLLLLLLL,L
53,2023-07-24 11:17:43,000,+11.06,+28.6,+5.268,+0.200,LLLLLLLL,L
54,2023-07-24 11:17:44,000,+11.05,+28.2,+5.267,+0.189,LLLLLLLL,L
55,2023-07-24 11:17:45,000,+11.04,+28.0,+5.267,+0.491,LLLLLLLL,L
56,2023-07-24 11:17:46,000,+11.04,+28.0,+5.266,+0.455,LLLLLLLL,L
57,2023-07-24 11:17:47,000,+11.04,+28.1,+5.267,+0.469,LLLLLLLL,L
58,2023-07-24 11:17:48,000,+11.06,+28.3,+5.269,+0.564,LLLLLLLL,L
59,2023-07-24 11:17:49,000,+11.05,+28.0,+5.267,+0.579,LLLLLLLL,L
60,2023-07-24 11:17:50,000,+11.06,+28.2,+5.268,+0.558,LLLLLLLL,L
61,2023-07-24 11:17:51,000,+11.05,+27.8,+5.266,+0.549,LLLLLLLL,L
62,2023-07-24 11:17:52,000,+11.05,+27.4,+5.265,+0.536,LLLLLLLL,L
63,2023-07-24 11:17:53,000,+11.06,+27.4,+5.267,+0.562,LLLLLLLL,L
64,2023-07-24 11:17:54,000,+11.05,+27.4,+5.268,+0.538,LLLLLLLL,L
65,2023-07-24 11:17:55,000,+11.06,+27.5,+5.268,+0.217,LLLLLLLL,L
66,2023-07-24 11:17:56,000,+11.05,+27.8,+5.269,+0.284,LLLLLLLL,L
67,2023-07-24 11:17:57,000,+11.07,+28.0,+5.270,+0.355,LLLLLLLL,L
68,2023-07-24 11:17:58,000,+11.05,+28.0,+5.269,+0.406,LLLLLLLL,L
69,2023-07-24 11:17:59,000,+11.06,+27.9,+5.270,+0.199,LLLLLLLL,L
70,2023-07-24 11:18:00,000,+11.06,+27.6,+5.270,+0.208,LLLLLLLL,L
71,2023-07-24 11:18:01,000,+11.06,+27.9,+5.271,+0.236,LLLLLLLL,L
72,2023-07-24 11:18:02,000,+11.07,+28.2,+5.271,+0.255,LLLLLLLL,L
73,2023-07-24 11:18:03,000,+11.05,+28.5,+5.276,+0.170,LLLLLLLL,L
74,2023-07-24 11:18:04,000,+11.05,+28.4,+5.276,+0.193,LLLLLLLL,L
75,2023-07-24 11:18:05,000,+11.06,+28.3,+5.277,+0.190,LLLLLLLL,L
76,2023-07-24 11:18:06,000,+11.06,+27.9,+5.279,+0.186,LLLLLLLL,L
77,2023-07-24 11:18:07,000,+11.05,+27.3,+5.276,+0.155,LLLLLLLL,L
78,2023-07-24 11:18:08,000,+11.05,+27.5,+5.276,+0.184,LLLLLLLL,L
79,2023-07-24 11:18:09,000,+11.03,+27.5,+5.276,+0.168,LLLLLLLL,L
80,2023-07-24 11:18:10,000,+11.04,+27.4,+5.276,+0.299,LLLLLLLL,L
81,2023-07-24 11:18:11,000,+11.03,+27.2,+5.275,+0.234,LLLLLLLL,L
82,2023-07-24 11:18:12,000,+11.04,+27.0,+5.277,+0.197,LLLLLLLL,L
83,2023-07-24 11:18:13,000,+11.04,+27.0,+5.278,+0.175,LLLLLLLL,L
84,2023-07-24 11:18:14,000,+11.05,+27.2,+5.279,+0.510,LLLLLLLL,L
85,2023-07-24 11:18:15,000,+11.07,+27.7,+5.281,+0.481,LLLLLLLL,L
86,2023-07-24 11:18:16,000,+11.05,+28.0,+5.278,+0.465,LLLLLLLL,L
87,2023-07-24 11:18:17,000,+11.06,+28.2,+5.279,+0.435,LLLLLLLL,L
88,2023-07-24 11:18:18,000,+11.04,+27.8,+5.279,+0.541,LLLLLLLL,L
89,2023-07-24 11:18:19,000,+11.04,+27.4,+5.279,+0.561,LLLLLLLL,L
90,2023-07-24 11:18:20,000,+11.03,+27.1,+5.282,+0.526,LLLLLLLL,L
91,2023-07-24 11:18:21,000,+11.03,+26.8,+5.282,+0.503,LLLLLLLL,L
92,2023-07-24 11:18:22,000,+11.03,+26.7,+5.283,+0.490,LLLLLLLL,L
93,2023-07-24 11:18:23,000,+11.00,+26.7,+5.282,+0.592,LLLLLLLL,L
94,2023-07-24 11:18:24,000,+11.01,+26.8,+5.281,+0.586,LLLLLLLL,L
95,2023-07-24 11:18:25,000,+11.03,+26.7,+5.280,+0.565,LLLLLLLL,L
96,2023-07-24 11:18:26,000,+11.02,+26.7,+5.281,+0.535,LLLLLLLL,L
97,2023-07-24 11:18:27,000,+11.03,+26.9,+5.281,+0.547,LLLLLLLL,L
98,2023-07-24 11:18:28,000,+11.05,+27.4,+5.282,+0.583,LLLLLLLL,L
99,2023-07-24 11:18:29,000,+11.06,+27.5,+5.283,+0.607,LLLLLLLL,L
100,2023-07-24 11:18:30,000,+11.03,+27.7,+5.280,+0.552,LLLLLLLL,L
101,2023-07-24 11:18:31,000,+11.03,+28.2,+5.281,+0.583,LLLLLLLL,L
102,2023-07-24 11:18:32,000,+11.04,+28.2,+5.281,+0.341,LLLLLLLL,L
103,2023-07-24 11:18:33,000,+11.04,+28.0,+5.281,+0.361,LLLLLLLL,L
104,2023-07-24 11:18:34,000,+11.04,+27.9,+5.281,+0.410,LLLLLLLL,L
105,2023-07-24 11:18:35,000,+11.04,+27.8,+5.281,+0.469,LLLLLLLL,L
106,2023-07-24 11:18:36,000,+11.04,+27.7,+5.279,+0.487,LLLLLLLL,L
107,2023-07-24 11:18:37,000,+11.04,+27.4,+5.279,+0.173,LLLLLLLL,L
108,2023-07-24 11:18:38,000,+11.06,+27.6,+5.279,+0.223,LLLLLLLL,L
109,2023-07-24 11:18:39,000,+11.02,+27.7,+5.280,+0.210,LLLLLLLL,L
110,2023-07-24 11:18:40,000,+11.02,+27.6,+5.283,+0.242,LLLLLLLL,L
111,2023-07-24 11:18:41,000,+11.03,+27.2,+5.283,+0.269,LLLLLLLL,L
112,2023-07-24 11:18:42,000,+11.02,+27.4,+5.282,+0.258,LLLLLLLL,L
113,2023-07-24 11:18:43,000,+11.04,+27.6,+5.283,+0.253,LLLLLLLL,L
114,2023-07-24 11:18:44,000,+11.04,+28.0,+5.286,+0.156,LLLLLLLL,L
115,2023-07-24 11:18:45,000,+11.05,+28.4,+5.287,+0.154,LLLLLLLL,L
116,2023-07-24 11:18:46,000,+11.04,+28.2,+5.287,+0.161,LLLLLLLL,L
117,2023-07-24 11:18:47,000,+11.07,+28.4,+5.290,+0.179,LLLLLLLL,L
118,2023-07-24 11:18:48,000,+11.04,+28.4,+5.288,+0.184,LLLLLLLL,L
119,2023-07-24 11:18:49,000,+11.05,+27.9,+5.290,+0.126,LLLLLLLL,L
120,2023-07-24 11:18:50,000,+11.05,+27.6,+5.292,+0.169,LLLLLLLL,L
121,2023-07-24 11:18:51,000,+11.03,+27.9,+5.292,+0.145,LLLLLLLL,L
122,2023-07-24 11:18:52,000,+11.04,+27.9,+5.289,+0.144,LLLLLLLL,L
123,2023-07-24 11:18:53,000,+11.06,+27.5,+5.289,+0.175,LLLLLLLL,L
124,2023-07-24 11:18:54,000,+11.04,+27.4,+5.289,+0.143,LLLLLLLL,L
125,2023-07-24 11:18:55,000,+11.06,+27.5,+5.293,+0.153,LLLLLLLL,L
126,2023-07-24 11:18:56,000,+11.04,+27.2,+5.294,+0.155,LLLLLLLL,L
127,2023-07-24 11:18:57,000,+11.05,+27.4,+5.295,+0.157,LLLLLLLL,L
128,2023-07-24 11:18:58,000,+11.05,+28.0,+5.295,+0.170,LLLLLLLL,L
129,2023-07-24 11:18:59,000,+11.04,+28.3,+5.293,+0.369,LLLLLLLL,L
130,2023-07-24 11:19:00,000,+11.04,+28.5,+5.289,+0.273,LLLLLLLL,L
131,2023-07-24 11:19:01,000,+11.05,+28.0,+5.291,+0.246,LLLLLLLL,L
132,2023-07-24 11:19:02,000,+11.06,+28.0,+5.292,+0.189,LLLLLLLL,L
133,2023-07-24 11:19:03,000,+11.04,+28.1,+5.290,+0.184,LLLLLLLL,L
134,2023-07-24 11:19:04,000,+11.07,+28.2,+5.290,+0.144,LLLLLLLL,L
135,2023-07-24 11:19:05,000,+11.05,+28.2,+5.300,+0.488,LLLLLLLL,L
136,2023-07-24 11:19:06,000,+10.99,+27.5,+5.299,+0.441,LLLLLLLL,L
137,2023-07-24 11:19:07,000,+11.02,+27.3,+5.295,+0.452,LLLLLLLL,L
138,2023-07-24 11:19:08,000,+11.03,+27.3,+5.294,+0.436,LLLLLLLL,L
139,2023-07-24 11:19:09,000,+11.00,+26.9,+5.288,+0.419,LLLLLLLL,L
140,2023-07-24 11:19:10,000,+11.02,+26.9,+5.294,+0.547,LLLLLLLL,L
141,2023-07-24 11:19:11,000,+11.01,+26.7,+5.286,+0.531,LLLLLLLL,L
142,2023-07-24 11:19:12,000,+11.02,+26.7,+5.289,+0.544,LLLLLLLL,L
143,2023-07-24 11:19:13,000,+11.03,+26.8,+5.288,+0.537,LLLLLLLL,L
144,2023-07-24 11:19:14,000,+11.03,+26.9,+5.289,+0.570,LLLLLLLL,L
145,2023-07-24 11:19:15,000,+11.01,+26.9,+5.289,+0.514,LLLLLLLL,L
146,2023-07-24 11:19:16,000,+11.00,+27.2,+5.293,+0.392,LLLLLLLL,L
147,2023-07-24 11:19:17,000,+11.01,+26.8,+5.292,+0.389,LLLLLLLL,L
148,2023-07-24 11:19:18,000,+11.04,+26.9,+5.292,+0.403,LLLLLLLL,L
149,2023-07-24 11:19:19,000,+11.02,+26.9,+5.294,+0.334,LLLLLLLL,L
150,2023-07-24 11:19:20,000,+11.01,+26.7,+5.295,+0.331,LLLLLLLL,L
151,2023-07-24 11:19:21,000,+11.02,+26.7,+5.296,+0.366,LLLLLLLL,L
152,2023-07-24 11:19:22,000,+11.03,+26.7,+5.296,+0.356,LLLLLLLL,L
153,2023-07-24 11:19:23,000,+11.04,+26.6,+5.296,+0.340,LLLLLLLL,L
154,2023-07-24 11:19:24,000,+11.01,+26.7,+5.301,+0.146,LLLLLLLL,L
155,2023-07-24 11:19:25,000,+11.01,+26.5,+5.300,+0.113,LLLLLLLL,L
156,2023-07-24 11:19:26,000,+11.02,+26.5,+5.299,+0.119,LLLLLLLL,L
157,2023-07-24 11:19:27,000,+11.02,+26.7,+5.299,+0.158,LLLLLLLL,L
158,2023-07-24 11:19:28,000,+11.00,+26.9,+5.299,+0.148,LLLLLLLL,L
159,2023-07-24 11:19:29,000,+11.04,+26.4,+5.299,+0.134,LLLLLLLL,L
160,2023-07-24 11:19:30,000,+11.02,+26.4,+5.300,+0.172,LLLLLLLL,L
161,2023-07-24 11:19:31,000,+11.02,+26.5,+5.301,+0.148,LLLLLLLL,L
162,2023-07-24 11:19:32,000,+11.02,+26.7,+5.302,+0.135,LLLLLLLL,L
163,2023-07-24 11:19:33,000,+11.02,+27.0,+5.300,+0.156,LLLLLLLL,L
164,2023-07-24 11:19:34,000,+11.02,+27.0,+5.303,+0.133,LLLLLLLL,L
165,2023-07-24 11:19:35,000,+11.01,+27.2,+5.299,+0.465,LLLLLLLL,L
166,2023-07-24 11:19:36,000,+11.02,+27.4,+5.301,+0.435,LLLLLLLL,L
167,2023-07-24 11:19:37,000,+11.03,+27.2,+5.301,+0.440,LLLLLLLL,L
168,2023-07-24 11:19:38,000,+11.02,+27.5,+5.300,+0.400,LLLLLLLL,L
169,2023-07-24 11:19:39,000,+11.02,+27.9,+5.301,+0.403,LLLLLLLL,L
170,2023-07-24 11:19:40,000,+11.02,+28.0,+5.301,+0.393,LLLLLLLL,L
171,2023-07-24 11:19:41,000,+11.02,+28.3,+5.302,+0.427,LLLLLLLL,L
172,2023-07-24 11:19:42,000,+11.02,+28.5,+5.303,+0.427,LLLLLLLL,L
173,2023-07-24 11:19:43,000,+11.01,+28.6,+5.299,+0.527,LLLLLLLL,L
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

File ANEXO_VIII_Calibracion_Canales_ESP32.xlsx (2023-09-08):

CALIBRACIÓN | HQ POWER DVM891
Valor patrón [V] | Valor entrada pin 26 (Irradiancia) ESP32 [V] | Valor patrón [V] | Valor entrada pin 35 (Temperatura) ESP32 [V]
0.00 | 0.00 | 0.00 | 0.00
0.26 | 0.14 | 0.24 | 0.09
0.26 | 0.14 | 0.24 | 0.09
0.26 | 0.14 | 0.24 | 0.09
0.26 | 0.14 | 0.24 | 0.12
0.26 | 0.14 | 0.24 | 0.12
0.26 | 0.14 | 0.24 | 0.12
0.26 | 0.14 | 0.24 | 0.07
0.26 | 0.14 | 0.24 | 0.10
0.26 | 0.14 | 0.24 | 0.11
0.26 | 0.14 | 0.24 | 0.11
0.26 | 0.15 | 0.24 | 0.12
0.26 | 0.15 | 0.24 | 0.08
0.26 | 0.15 | 0.24 | 0.09
0.26 | 0.15 | 0.24 | 0.14
0.26 | 0.16 | 0.24 | 0.10
0.26 | 0.16 | 0.24 | 0.10
0.26 | 0.17 | 0.24 | 0.06
0.26 | 0.17 | 0.39 | 0.24
0.26 | 0.17 | 0.39 | 0.24
0.26 | 0.13 | 0.39 | 0.24
0.41 | 0.30 | 0.39 | 0.24
0.41 | 0.30 | 0.39 | 0.24
0.41 | 0.30 | 0.39 | 0.21
0.41 | 0.30 | 0.39 | 0.23
0.41 | 0.30 | 0.39 | 0.18
0.41 | 0.30 | 0.39 | 0.25
0.41 | 0.30 | 0.39 | 0.28
0.41 | 0.30 | 0.39 | 0.20
0.41 | 0.30 | 0.39 | 0.21
0.41 | 0.30 | 0.39 | 0.26
0.41 | 0.29 | 0.39 | 0.27
0.41 | 0.29 | 0.39 | 0.30
0.41 | 0.29 | 0.62 | 0.48
0.41 | 0.28 | 0.62 | 0.48
0.41 | 0.28 | 0.62 | 0.48
0.41 | 0.28 | 0.62 | 0.48
0.41 | 0.31 | 0.62 | 0.48
0.41 | 0.31 | 0.62 | 0.46
0.41 | 0.32 | 0.62 | 0.46
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

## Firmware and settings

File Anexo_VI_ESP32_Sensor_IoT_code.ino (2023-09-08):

//Autor: Ibrahim Plasencia Castilla
//Referencias:
//https://docs.espressif.com/projects/esp-idf/en/latest/esp32/
// https://github.com/espressif/arduino-esp32/blob/master/libraries/BluetoothSerial/src/BluetoothSerial.h
//https://www.cplusplus.com/reference/cmath/pow/
//https://randomnerdtutorials.com/esp32-bluetooth-classic-arduino-ide/
//https://randomnerdtutorials.com/esp32-adc-analog-read-arduino-ide/
//https://en.wikipedia.org/wiki/Thermistor#Calculation_of_temperature_and_thermal_tolerances

//Descripción: Código empleado para conocer la dirección MAC del dispositivo ESP32, establecer una comunicación Bluetooth con otro dispositivo, obtener datos de irradiancia y temperatura, asi como del error cometido en el cálculo de dicha temperatura, su envío a través de Bluetooth, y control del estado de LEDs de encendido/apagadom y de estado de conexión Bluetooth
//Fecha de creación: 27 de marzo de 2023

/////////////////////////////////////////////////////////////////////////////////////////////////////////////////////////////////////////////////////////////////////////////////////////////////////////////////////////////////////////////////////////////////////////////////////////////////////////////////////////////////////////////////////////////////////////////////////////
//Librerías para el ESP32
#include "BluetoothSerial.h" //Librería que contiene las declaraciones y definiciones necesarias para trabajar con Bluetooth en el ESP32
#include "esp_bt_device.h" //Librería que contiene el archivo de cabecera "esp_bt_device.h" que contiene las funciones y definiciones relacionadas con el manejo del Bluetooth en el ESP32
#include "math.h" //Librería que contiene funciones matemáticas, como la función "pow()"

//Comprobación de si la configuración Bluetooth está habilitada antes de compilar el código
#if !defined(CONFIG_BT_ENABLED) || !defined(CONFIG_BLUEDROID_ENABLED) //se comprueba que están definidos los macros necesarios
#error Bluetooth is not enabled! Please run `make menuconfig` to and enable it //si no están habilitados los macros se pide al usuario que ejecute "make menuconfig" para habilitarlo
#endif

BluetoothSerial SerialBT; //Se crea instancia llamada SerialBT de la clase BluetoothSerial, empleada para establecer y administrar la comunicación Bluetooth

//Obtención de la dirección MAC del dispositivo ESP32 en formato hexadecimal, para identificarlo dentro de la red ("XX:XX:XX:XX:XX:XX")
void printDeviceAddress(){

  const uint8_t* point = esp_bt_dev_get_address(); //esta función devuelve un puntero a una matriz que contiene los bytes de la dirección MAC

  for (int i=0; i<6; i++){ //se itera sobre los 6 bytes de los que se compone la dirección MAC (en redes Ethernet y Bluetooth la dirección MAC se compone de 6 bytes, donde cada byte representa un valor hexadecimal)

    char str[3]; //arreglo de 3 caracteres (2 para el valor hezadecimal y 1 para el terminador nulo '\0' para marcar el final)

    sprintf(str, "%02X", (int)point[i]); //Se imprimen los bytes de la dirección MAC, de al menos dos dígitos, y si es solo uno, se completa con ceros a la izquierda
    Serial.print(str); //Se imprime la cadena a través de la UART de la placa ESP32

    if(i<5){
      Serial.print(":"); //entre byte y byte de la dirección MAC se incluye separador ":"
    }
  }
}

// Definición de pines empleados
const int pinIrradiancia = 26;
const int pinTemperatura = 35;
const int LED_ON_OFF = 16; //LED de estado de alimentación de la placa ("HIGH-encendida" y "LOW-apagada")
const int LED_BT = 17; //LED de estado de conexión Bluetooth ("HIGH- conectado" y "LOW-desconectado")

//Variables asociadas con el encendido de los LEDs
bool isConnected = false; //Variable que indica que si la placa está conectada a Bluetooth o no

//Variables asociados a la cuenta de tiempo transcurrido
unsigned long tiempoAnterior = 0;
const unsigned long intervalo = 500; // Intervalo de tiempo entre lecturas en milisegundos (en este caso, 500ms)

//Variables globales asociados a la lectura de la irradiancia solar
const float Vmax=3.3; //Tension de alimentación de referencia
const float Kirrad = 53.252; //cte de calibración de la célula solar (relación irradiancia solar/tensión de salida célula solar obtenida mediante cañibración experimental con piranómetro)
const float Gain = 106.50; //Ganancia calculada para el amplificador de instrumentación (Vout/Vin)
const float Kti=1.0125; //Cte de calibración del pin de entrada de la ESP32 asociado al canal de irradiancia (pin 26)

//Variables globales asociados a la lectura de temperatura extraídas de la documentación de referencia para el sensor empleado
const int R1= 4700; //Resistencia de 4.7 kOhm (resistencia de referencia a 25 grados centígrados)
const int Bvalue= 3977; //Valor de B25/85 (tolerancia en B) extraído de la docu de referencia
const float X = 5; //[%] Tolerancia a una temperatura de referencia de 25ºC
const float Ktt=1.0221; //cte de calibración del pin de la ESP32 asociado al canal de temperatura (pin 35)

//Coeficientes para el cálculo de temperatura (extraído del catálogo de termistores de "Philips Components" - NTC thermistors, accuracy line 2322 640 6... )
const float A= 3.353832e-03;
const float B= 2.569355e-04;
const float C= 2.626311e-06;
const float D= 0.675278e-07;

//CALCULO DE LA DESVIACIÓN DE TEMPERATURA CON RESPECTO A LA TEMPERATURA NOMINAL
//Se define la tabla de valores que relaciona la temperatura calculada con la desviación de resistencia debido a la tolerancia en B (Y), y el coeficiente de temperatura (TC)
//(extraída de las columnas "Tamb", "AR DUE TO B-TOLERANCE (%)" y "TC (%/K)" de la "Table 3" del catálogo de termistores de "Philips Components" - NTC thermistors, accuracy line 2322 640 6... ))

float tabla[][3] ={ //tabla donde cada fila tiene 3 elementos flotantes
    {0, 0.89, 5.08},
    {5, 0.70, 4.92},
    {10, 0.52, 4.78},
    {15, 0.34, 4.64},
    {20, 0.17, 4.50},
    {25, 0.00, 4.37},
    {30, 0.16, 4.25},
    {35, 0.32, 4.13},
    {40, 0.47, 4.02},
    {45, 0.62, 3.91},
    {50, 0.77, 3.80},
    {55, 0.91, 3.70},
    {60, 1.05, 3.60},
    {65, 1.18, 3.51},
    {70, 1.31, 3.42},
    {75, 1.44, 3.33},
    {80, 1.57, 3.25},
    {85, 1.69, 3.16},
    {90, 1.81, 3.09},
    {95, 1.93, 3.01},
    {100, 2.04, 2.94}
};

int tablaSize=sizeof(tabla) / sizeof(tabla[0]); //se obtiene el número de elementos en el arreglo "tabla" como el cociente entre el tamaño total del arreglo y el tamaño de un elemento en bytes

//Función que recibe como entrada la tabla anterior y el valor de temperatura calculado, y devuelve los valores Y (Second_column_interp), TC (Third_column_interp) para el cálculo de la desviación de temperatura DT con respecto al valor nominal
void buscar_valor_tabla(float tabla[][3], int tablaSize, float Temperatura, float& Y, float& TC){ //Los parámetros "Y" y "TC" se pasan como parámetros de salida de tipo flotante por referencia "float& ", lo que significa que los valores se modifican dentro de la función y dichos cambios serán visibles fuera de ella, en el lugar en el que se llamó
    //Búsqueda del valor exacto en la tabla
    for (int i = 0; i < tablaSize; i++) {
      if (abs(tabla[i][0] - Temperatura)<0.2){ //aquí se indica que si la diferencia entre el valor de temperatura calculado, y el mostrado en la Tabla es menor a 0.1ºC, puede tomar directamente los valores de Y, TC correspondientes (es una comparación de igualdad aproximada)
        Y = tabla[i][1];
        TC = tabla[i][2];  //Se devuelven los valores de las otras dos columnas en función del valor de temperatura
        return;
      }
    }

    //Interpolación lineal si no se encuentra el valor exacto de temperatura en la tabla
    for (int i = 0; i < tablaSize - 1; i++) {
      if (tabla[i][0] < Temperatura && Temperatura < tabla[i + 1][0]) {

        //Interpolación lineal para obtener el valor de Y (resistance deviation due to B-tolerance)
        float temp1 = tabla[i][0];
        float Y1 = tabla[i][1];
        float temp2 = tabla[i + 1][0];
        float Y2 = tabla[i + 1][1];
        Y = Y1 + (Y2 - Y1) * (Temperatura - temp1) / (temp2 - temp1);

        //Interpolación lineal para obtener el valor de TC (temperature coefficient)
        float TC1 = tabla[i][2];
        float TC2 = tabla[i + 1][2];
        TC = TC1 + (TC2 - TC1) * (Temperatura - temp1) / (temp2 - temp1);

        return;
      }
    }

  // Retorno de un valor inválido si el valor está fuera del rango de la tabla, como marcadores
  Y = -1.0;
  TC = -1.0;
}

void setup() {

  //Se inicializa el LED de encendido/apagado a nivel alto
  pinMode(LED_ON_OFF, OUTPUT);
  digitalWrite(LED_ON_OFF, HIGH); //Al alimentar el sistema, se va a encender el LED, y al desconectarlo se va a apagar

  //CONFIG COMUNICACIÓN BLUETOOTH
  //Se inicializa la comunicación Serial
  Serial.begin(115200); //velocidad de la transmisión de datos en baudios
  Serial.println("\n---Start---\n");
  SerialBT.begin("ESP32"); //Nombre del dispositivo Bluetooth
  
  Serial.println("El dispositivo se ha iniciado, ¡ahora puedes emparejarlo mediante Bluetooth!");
  Serial.println("Nombre del dispositivo: ESP32");
  Serial.print("BT MAC: ");
  printDeviceAddress(); //dirección MAC del dispositivo
  Serial.println();//Se imprime salto de línea

  //Mantener apagado el LED_BT al inicio, hasta que no se establezca el emparejamiento con el otro dispositivo
  pinMode(LED_BT, OUTPUT);
  digitalWrite(LED_BT, LOW);

  //Configuración de los pines asociados con la lectura de irradiancia y temperatura como entradas
  pinMode(pinIrradiancia, INPUT);
  pinMode(pinTemperatura, INPUT);
}

void loop() {

  //Se obtiene el tiempo actual transcurrido
  unsigned long tiempoActual = millis();

  //Se verifica si ha pasado el intervalo de tiempo deseado entre tomas de datos
  if (tiempoActual - tiempoAnterior >= intervalo) {

    //MEDIDA DE IRRADIANCIA SOLAR
    int valorADCIrrad = analogRead(pinIrradiancia); //se obtiene la lectura del ADC en el pin al que se conecta el módulo solar
    float valorTensionIrrad = (valorADCIrrad *Vmax / 4095)*Kti; // Se traduce el valor obtenido del conversor ADC en un valor de tensión. Se divide el valor de salida del ADC entre 4095, porque el ADC es de 12 bits, y se multiplica por 3.3V porque el sistema se alimenta con 3.3V (valorde tensión de referencia)
    float Irradiancia = valorTensionIrrad *pow(10,3) /Gain *Kirrad; //Se obtiene el dato de irradiancia solar

    //MEDIDA DE TEMPERATURA
    int valorADCTemp = analogRead(pinTemperatura); //se obtiene la lectura del ADC en el pin al que se conecta el termistor
    float valorTensionTemp = (valorADCTemp *Vmax / 4095)*Ktt; //Seria el denominado Vadc en la memoria
    float R2=(valorTensionTemp *R1)/(Vmax-valorTensionTemp); //Resistencia del termistor (NTC) que se traduce en un valor de temperatura
    //Cálculo de la temperatura nominal usando la ecuación de Steinhart-Hart
    float E = log(R2/R1);
    float TemperaturaK = pow(A + B*E + C*pow(E,2) + D*pow(E,3),-1); //Temperatura nominal en Kelvin (K) en función de la resistencia R2 del termistor (NTC)
    float Temperatura= TemperaturaK - 273.15; //Temperatura en ºC

    //Cálculo de la desviación de temperatura con respecto a la nominal
    float Y, TC;
    buscar_valor_tabla(tabla, tablaSize, Temperatura, Y, TC);
    float Z = X+Y;
    float DT = Z/TC; //Desviación de temperatura calculada

    // Envío de los valores de irradiancia y temperatura en un ÚNICO mensaje Bluetooth
    String mensaje = String(Irradiancia) + " " + String(Temperatura) + " " + String(DT)+ " ";
    SerialBT.print(mensaje);

    // Actualizar el tiempo anterior
    tiempoAnterior = tiempoActual;
  }

  //CONTROL DEL ENCENDIDO DEL LED DE ESTADO DE LA CONEXIÓN BLUETOOTH
  //Código para verificar la conexión Bluetooth y controlar el encendido de LED_BT
  if (SerialBT.connected()) {
    // Si está conectado y no estaba conectado previamente, encender el LED_BT
    if (!isConnected) {
      isConnected = true;
      digitalWrite(LED_BT, HIGH);
    }
  } else {
    // Si no está conectado y estaba conectado previamente, apagar el LED_BT
    if (isConnected) {
      isConnected = false;
      digitalWrite(LED_BT, LOW);
    }
  }
}

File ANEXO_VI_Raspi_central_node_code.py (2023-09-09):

# Archivo: Code_TFM_Ibrahim_Plasencia.py
# Autor: Ibrahim Plasencia Castilla
# Referencias para el código:
# Comunicacion Bluetooth--> https://github.com/karulis/pybluez/examples/simple/rfcomm-client.py
# Orientacion magnetica--> https://github.com/ControlEverythingCommunity/HMC5883/blob/master/Python/HMC5883.py
# Localizacion geográfica--> https://stackoverflow.com/questions/32191380/python-subprocess-check-output-with-pipeline
# Escritura en ficheros --> https://www.w3schools.com/python/python_file_write.asp
 
# Descripción: Código destinado a la recepción y tratamiento de datos de irradiancia y temperatura mediante comunicacion Bluetooth, y adquisición de datos de localización (GPS) y orientacion (compass)
# Fecha de creación: 2 de mayo de 2023
 
from bluetooth import *  #para trabajar con los elementos definidos en el módulo 'bluetooth'
from datetime import datetime  #para trabajar con fechas y horas
import time  #para trabajar con funciones relacionadas con el tiempo
import sys  #para trabajar con funciones y variables relacionadas con el intérprete de Python
import os  #para interactuar con el sistema operativo (acceder a archivos y directorios, etc)
import smbus  #para comunicarse con dispositivos I2C (en este caso la brújula)
import math  #para trabajar con funciones matemáticas
import subprocess  #para crear procesos secundarios y realizar operaciones en la línea de comandos
import json  #para trabajar con datos en formato JSON
 
# Matriz para almacenar los datos obtenidos en esta aplicación
datos = []
 
#Frecuencia de guardado de datos, en este caso coincidiendo con la frecuencia de recepción de mensajes de la ESP32 (500ms)
intervalo_guardado=0.5
 
#Declinación magnética (en grados) en la ubicación de los ensayos para el cálculo de la orientación magnética (brújula)- ACTUALIZAR SI ES NECESARIO (fuente: https://www.ngdc.noaa.gov/geomag/calculators/magcalc.shtml?)
declination = 0.17 # MADRID
#declination = -3.57 # ISLAS CANARIAS
 
 
#Función para guardar los datos obtenidos en un archivo de texto (txt) para su posterior tratamiento y análisis
def guardar_datos(lat, lon, orient, cardinal_direction, irradiancia, temperatura, DT): #La función recibe como argumentos la ubicación y orientación obtenidas del módulo BN-880 GPS. En cuanto a los datos de irradiancia y temperatura los toma de la matriz global "datos"
 
    ruta = "/home/ibrahimplasenciatfm/datos.txt" #Ruta específica donde se desea almacenar el fichero txt creado (MODIFICAR SEGÚN UBICACIÓN DESEADA)
    encabezado1 = "Datos suministrados por el nodo sensor (ESP32, vía Bluetooth), y el módulo GPS (comunicacón I2C/UART, Raspberry Pi) para el análisis de la Irradiancia Solar recibida en un Vehículo con Integración Fotovoltaica, en un determinado periodo de conducción por carretera, y estudio de la influencia de la temperatura de la célula solar en los resultados obtenidos"
    encabezado2 = "Fecha Hora Latitud[°] Longitud[°] Orientación Geográfica[°] IrradianciaSolar[W/m2] Temperatura[°] Desv.Temperatura[°]"
   
    if not os.path.isfile(ruta): #Se verifica si el archivo de texto ya existe o no. Si no existe, se ejecutan las siguientes líneas
       
        with open(ruta, "w") as file: #se abre el archivo en 'modo escritura' y se escriben los encabezados definidos anteriormente
            file.write(encabezado1 + "\n")
            file.write(encabezado2 + "\n")
           
    datos_guardar = datos.copy() #Se crea una copia de la lista de datos recolectados previamente
   
    with open(ruta, "a") as file: #se abre el archivo en 'modo de escritura adicional', lo que significa que los nuevos datos se agregan al final sin sobreescribir los datos existentes
        for fila in datos:
            fila_str=datetime.now().strftime("%d-%m-%Y %H:%M:%S ") #Se obtienen la fecha y hora actuales, que se asocian a cada conjunto de datos recogido
            fila_str += f"{lat:.6f} {lon:.6f} {orient:.2f} {cardinal_direction} {irradiancia:.2f} {temperatura:.2f} {DT:.2f}" #Se añaden a continuación datos de latitud, longitud, orientación, dirección cardinal, irradiancia, temperatura y desviación de temperatura
            file.write(fila_str + "\n") # se escribe el conjunto de datos y se introduce salto de línea en el archivo
   
        file.flush() #se fuerza la escritura en el archivo datos.txt
   
    datos.clear() #se vacía la lista 'datos' después de que han sido escritos para asegurarnos de que no vuelvan a ser incluidos en futuras escrituras
           
    #Se comprueba que el archivo se ha creado correctamente
    if os.path.isfile(ruta):
       
        print("Archivo guardado en: ", ruta)
       
    else:
       
        print("No se pudo crear el archivo en la ruta especificada.")
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
